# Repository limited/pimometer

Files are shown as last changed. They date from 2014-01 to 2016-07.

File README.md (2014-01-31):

pimometer
=========
=======
## Remote Thermocouple Monitor

### Goal 
PCB to report temperature from 4 k-type thermocouples over wireless, for viewing on a smartphone. 
* _Form Factor_: Raspberry Pi Shield
* _Power Source_: Initially battery powered with on/off switch. 
** Future: solar or thermoelectric generator(TEG) using heat from oven.
* _Thermocouple Measurement_: MAX31855 [Datasheet](http://datasheets.maximintegrated.com/en/ds/MAX31855.pdf) via SPI in an SO-8 package
* _Wireless Connection_: WiFi Dongle
* _Configuration/Display_: via SD Card 
** LEDs for display- 1 LED for wireless connection
* Smartphone Display: Ideally would be accessible across multiple smartphone platforms, so no native app. 
** Better to have a webserver run on the device itself, i.e. Flask

### Design
#### Raspberry Pi pinout
* Clock: 11 
* MISO: 9
* CS1: 18 
* CS2: 23
* CS3: 24
* CS4: 25
* Also need +3.3V and ground available to shield
 
#### Software Design
* When Flask receives request for current temperatures, 
o

#### Service installation
chmod 755 nodejs
sudo cp nodejs /etc/init.d
sudo update-rc.d nodejs defaults

### Avahi Installation
sudo apt-get install avahi-daemon
sudo insserv avahi-daemon

#### Cost Comparison
Component  |  Raspberry Pi  | Arduino (TC shield + wifi breakout)
-----------+----------------+-------------------------------------
Controller |   $35          |    $7
Crystal    |                |    $1
Regulator  |                |    $2
Wifi       |   $15          |    $35
SD card    |   $8           |    
------------------------------------------------------------------
Subtotal   |   $58          |    $45

TC shield
------------
4xTC       |              $32
Custom PCB |              $15?

Enclosure    |
LiPo Battery | 
LiPo Charger |

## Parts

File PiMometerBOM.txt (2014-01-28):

Partlist exported from /Users/efriedri/Dropbox/eagle/PiMometer/PiMometer.sch at 11/29/13 10:36 PM

(M) Mouser
(SF) Sparkfun

Supplier	Part      Value               Device                  Package             Description                          PROD_ID   VALUE
M		C1        10uF                10UF50V20%(1210)        1210                16V 1210 10uF 10% MLCC	       810-C3225X7R1C106K 10uF 
M		C2        0.1uF               0.1UF-100V-10%(0603)    0603-CAP            16V 0603 .1uF 5% MLCC                77-VJ0603Y104JXJPBC 0.1uF
M		C3        0.1uF               0.1UF-100V-10%(0603)    0603-CAP            16V 0603 .1uF 5% MLCC                77-VJ0603Y104JXJPBC 0.1uFM
M		C4        0.1uF               0.1UF-100V-10%(0603)    0603-CAP            16V 0603 .1uF 5% MLCC                77-VJ0603Y104JXJPBC 0.1uF
M		C5        0.1uF               0.1UF-100V-10%(0603)    0603-CAP            16V 0603 .1uF 5% MLCC                77-VJ0603Y104JXJPBC 0.1uF
M		C6        10uF                10UF50V20%(1210)        1210                16V 1210 10uF 10% MLCC               810-C3225X7R1C106K 10uF                                    
SF		GPIO1     2X132X13            2X132X13                2X13                PRT-11490                            PRT-11490                                                      
M		IC1       MAX31855            MAX31855 		      SO08      	  MAX31855KASA+                                                              
M		IC2       MAX31855            MAX31855                SO08                MAX31855KASA+                                                    
M		IC3       MAX31855            MAX31855                SO08                MAX31855KASA+                                       
M		IC4       MAX31855            MAX31855                SO08                MAX31855KASA+                                       
SF		JP1       M022.54MM_SCREWTERM M022.54MM_SCREWTERM     1X02_2.54_SCREWTERM PRT-10571				PRT-10571	                
SF		JP2       M022.54MM_SCREWTERM M022.54MM_SCREWTERM     1X02_2.54_SCREWTERM PRT-10571				PRT-10571
SF		JP3       M022.54MM_SCREWTERM M022.54MM_SCREWTERM     1X02_2.54_SCREWTERM PRT-10571				PRT-10571
SF		JP4       M022.54MM_SCREWTERM M022.54MM_SCREWTERM     1X02_2.54_SCREWTERM PRT-10571				PRT-10571
SF 		JP5       M022.54MM_SCREWTERM M022.54MM_SCREWTERM     1X02_2.54_SCREWTERM PRT-10571				PRT-10571
SF		R1        10K                 10KOHM1/10W1%(0603)0603 0603-RES            RES-00824                            PRT-11246 10K        
SF 		R2        10K                 10KOHM1/10W1%(0603)0603 0603-RES            RES-00824                            PRT-11246 10K
SF 		R3        10K                 10KOHM1/10W1%(0603)0603 0603-RES            RES-00824                            PRT-11246 10K  
SF 		R4        10K                 10KOHM1/10W1%(0603)0603 0603-RES            RES-00824                            PRT-11246 10K  
SF 		R5        10K                 10KOHM1/10W1%(0603)0603 0603-RES            RES-00824                            PRT-11246 10K  
SF 		R6        10K                 10KOHM1/10W1%(0603)0603 0603-RES            RES-00824                            PRT-11246 10K  
SF 		R7        10K                 10KOHM1/10W1%(0603)0603 0603-RES            RES-00824                            PRT-11246 10K  
SF 		R8        10K                 10KOHM1/10W1%(0603)0603 0603-RES            RES-00824                            PRT-11246 10K  
SF 		R9        10K                 10KOHM1/10W1%(0603)0603 0603-RES            RES-00824                            PRT-11246 10K  
SF 		R10       10K                 10KOHM1/10W1%(0603)0603 0603-RES            RES-00824                            PRT-11246 10K  
SF 		R11       10K                 10KOHM1/10W1%(0603)0603 0603-RES            RES-00824                            PRT-11246 10K  
N/A		STANDOFF1 STAND-OFF           STAND-OFF               STAND-OFF           #4 Stand Off                                        
N/A		STANDOFF2 STAND-OFF           STAND-OFF               STAND-OFF           #4 Stand Off                                        
N/A		STANDOFF4 STAND-OFF           STAND-OFF               STAND-OFF           #4 Stand Off

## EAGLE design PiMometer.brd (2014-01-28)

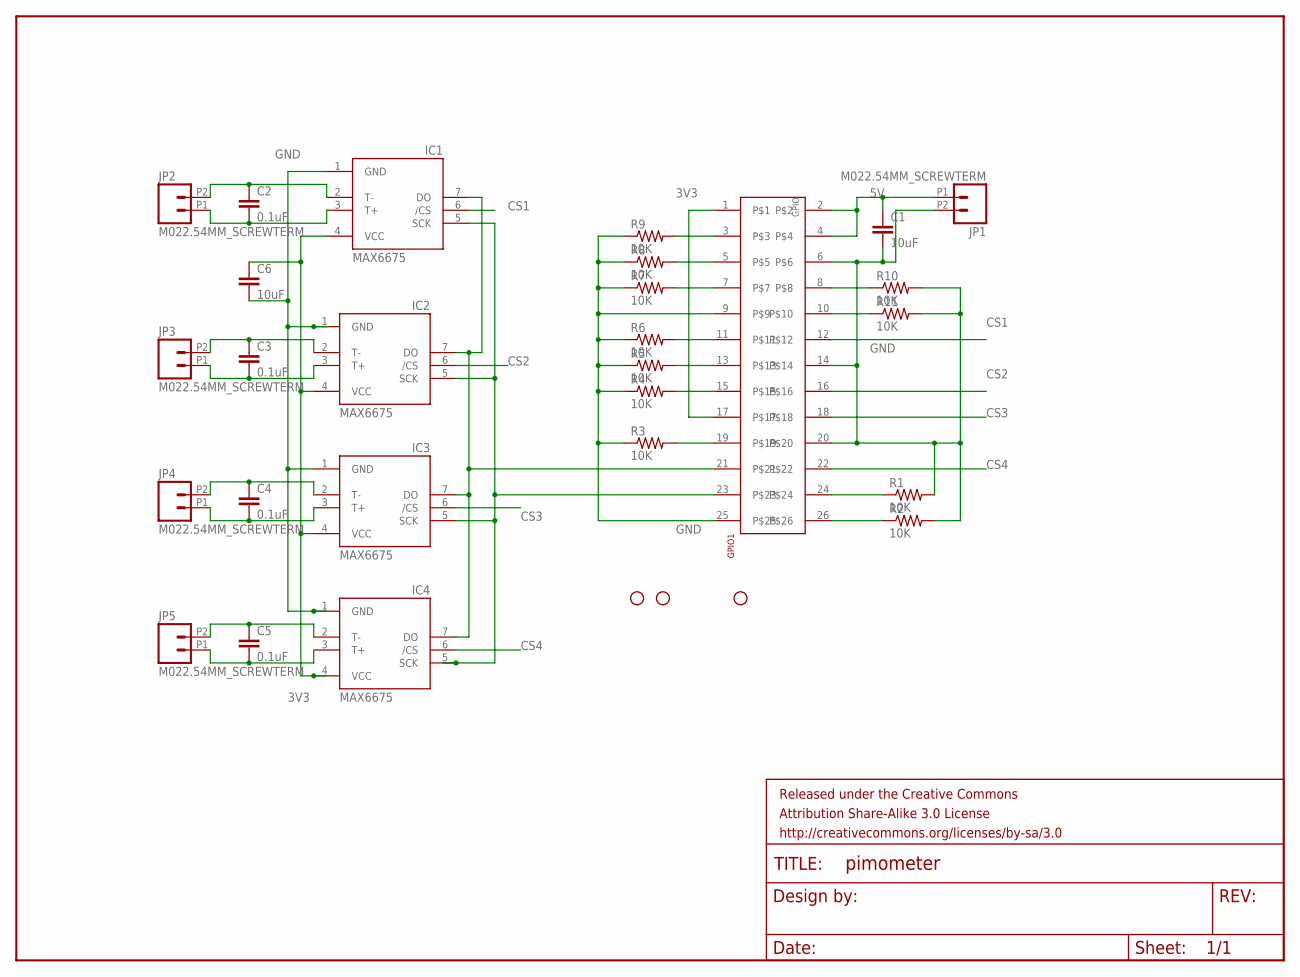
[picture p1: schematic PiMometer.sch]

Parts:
C1, C6: 10uF; 1210
C2, C3, C4, C5: 0.1uF; 0603-CAP
FRAME1: FRAME-LETTER; CREATIVE_COMMONS
GPIO1: 2X132X13; 2X13
IC1, IC2, IC3, IC4: MAX6675; SO08
JP1, JP2, JP3, JP4, JP5: M022.54MM_SCREWTERM; 1X02_2.54_SCREWTERM
R1, R2, R3, R4, R5, R6, R7, R8, R9, R10, R11: 10K; 0603-RES
STANDOFF1, STANDOFF2, STANDOFF4: STAND-OFF

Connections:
3V3: C6.1, GPIO1.1, GPIO1.17, IC1.4 (VCC), IC2.4 (VCC), IC3.4 (VCC), IC4.4 (VCC)
5V: C1.1, GPIO1.2, GPIO1.4, JP1.P1 (1)
CS1: GPIO1.12, IC1.6 (/CS)
CS2: GPIO1.16, IC2.6 (/CS)
CS3: GPIO1.18, IC3.6 (/CS)
CS4: GPIO1.22, IC4.6 (/CS)
GND: C1.2, C6.2, GPIO1.6, GPIO1.9, GPIO1.14, GPIO1.20, GPIO1.25, IC1.1 (GND), IC2.1 (GND), IC3.1 (GND), IC4.1 (GND), JP1.P2 (2), R1.2, R2.2, R3.1, R4.1, R5.1, R6.1, R7.1, R8.1, R9.1, R10.2, R11.2
unnamed: GPIO1.21, IC1.7 (DO), IC2.7 (DO), IC3.7 (DO), IC4.7 (DO)
unnamed: GPIO1.23, IC1.5 (SCK), IC2.5 (SCK), IC3.5 (SCK), IC4.5 (SCK)
unnamed: GPIO1.24, R1.1
unnamed: GPIO1.26, R2.1
unnamed: C2.1, IC1.2 (T-), JP2.P2 (2)
unnamed: C2.2, IC1.3 (T+), JP2.P1 (1)
unnamed: GPIO1.3, R9.2
unnamed: GPIO1.5, R8.2
unnamed: GPIO1.7, R7.2
unnamed: GPIO1.11, R6.2
unnamed: GPIO1.13, R5.2
unnamed: GPIO1.15, R4.2
unnamed: GPIO1.19, R3.2
unnamed: GPIO1.8, R10.1
unnamed: GPIO1.10, R11.1
unnamed: C3.1, IC2.2 (T-), JP3.P2 (2)
unnamed: C3.2, IC2.3 (T+), JP3.P1 (1)
unnamed: C4.1, IC3.2 (T-), JP4.P2 (2)
unnamed: C4.2, IC3.3 (T+), JP4.P1 (1)
unnamed: C5.1, IC4.2 (T-), JP5.P2 (2)
unnamed: C5.2, IC4.3 (T+), JP5.P1 (1)

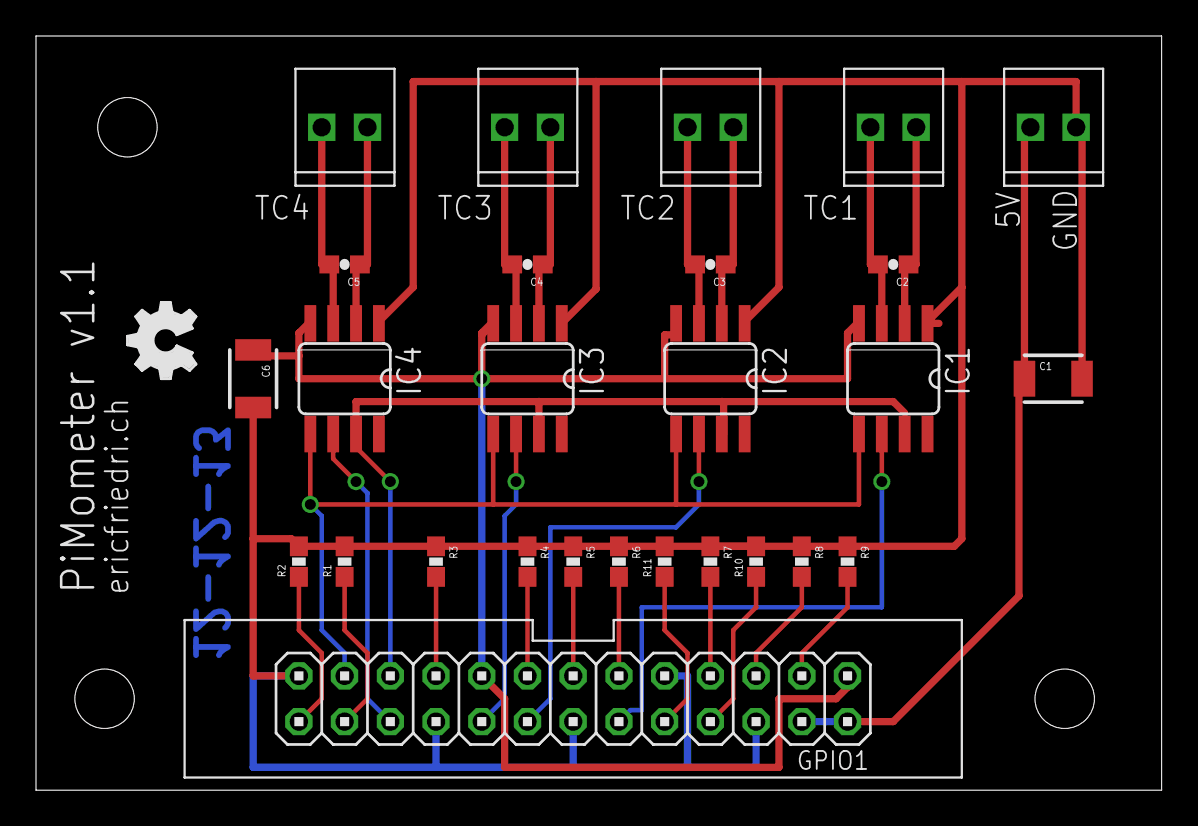
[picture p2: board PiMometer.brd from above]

Board: 2 copper layers, 62.5 x 41.9 mm, 32 parts (0 on the bottom side), 28 nets.

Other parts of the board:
U$1: OSHW_FILLX150_NOTEXT

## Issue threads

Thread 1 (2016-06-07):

Purchase

a-kress, 2016-06-07:
Is there anywhere I can purchase one of these boards? With or without components.

limited, 2016-06-08:
Not right now, sorry. Would you like to see it on Tindie or somewhere similar?

(I have one unpopulated board somewhere in my basement that I would send you, will let you know if I can find it)

a-kress, 2016-06-08:
I'd gladly pay you for it!

If not, no sweat. I may try to upload the eagle files to 123dcircuits.com.
I've never actually purchased a prototype board like this so I'm really
looking for the simplest solution.

Thanks!

On Wed, Jun 8, 2016 at 8:06 AM, Eric Friedrich <notifications@github.com>
wrote:

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

--

Adam Kress
akress.com

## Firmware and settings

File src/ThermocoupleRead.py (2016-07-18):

#!/usr/bin/env python
#
# Bitbang'd SPI interface with a MAX31855 TC->SPI device
#  Connections are:
#     CLK => 18  
#     DOUT => 23 (chip's data out, RPi's MISO)
#     CS => 24 

import RPi.GPIO as GPIO
import math
import time
import sys

MISO = 9 
CS_ARRAY = [18, 23, 24, 25]
CLK = 11 

def setupSpiPins():
    ''' Set pins as an output except MISO (Master Input, Slave Output)'''
    GPIO.setup(CLK, GPIO.OUT)
    GPIO.setup(MISO, GPIO.IN)
    for cs in CS_ARRAY:
      GPIO.setup(cs, GPIO.OUT)
    
    GPIO.output(CLK, GPIO.LOW)
    for cs in CS_ARRAY:
      GPIO.output(cs, GPIO.HIGH)
     

def readTemp(miso):
    
    tcValue = recvBits(miso, 32)
    #print "TC value: %x" % (tcValue)

    if (tcValue & 0x8):
      return 0 #"ERROR: Reserved bit 3 is 1" 

    if (tcValue & 0x20000):
      return 0 #"ERROR: Reserved bit 17 is 1" 

    if (tcValue & 0x10000):
      if (tcValue & 0x1):
        return 0 #"ERROR: Open Circuit"
      if (tcValue & 0x2):
        return 0 #"ERROR: Short to GND"
      if (tcValue & 0x4):
        return 0 #"ERROR: Short to Vcc"

    internal = (tcValue >> 4) & 0xFFF
    #print "Internal: %fC" % (internal*.0625)
    #print "Internal: %fF" % (internal*.0625*9.0/5.0+32)


    tcValue = tcValue >> 18

    temp = tcValue & 0x3FFF
    if (tcValue & 0x2000):
      temp = temp | 0xC000

    temp = temp * 0.25
    return temp
    
def recvBits(cs, numBits):
    '''Receives arbitrary number of bits'''
    retVal = 0

    # Start the read with chip select low
    GPIO.output(cs, GPIO.LOW)
    
    for bit in range(numBits):
        # Pulse clock pin 
        GPIO.output(CLK, GPIO.HIGH)
        
        # Advance input to next bit
        retVal <<= 1

        # Read 1 data bit in
        if GPIO.input(MISO):
            #print 31-bit, "1"
            retVal |= 0x1
        #else:
	#    print 31-bit, "0"
        
        GPIO.output(CLK, GPIO.LOW)
        time.sleep(.001)
    
    # Set chip select high to end the read
    GPIO.output(cs, GPIO.HIGH)

    return (retVal)

def convertTypeJToTypeK(temp):
    ''' Output temperature based on a Type J Thermocouple. 

        Theory: 
          The output temperature for a thermocouple is based on a voltage
          difference across the device. To use a Type J Thermocouple with the
          MAX31855K measurement sensor, do the following:
           1) Use the ITS-90 Type-K Direct Polynomial to find the 
              thermoelectric voltage from the reported temperature
           2) Use the ITS-90 Type-J Inverse Polynomial to find the
              temperature from the computed thermoelectric voltage
          NB: If polynomials are too hard to compute, use a lookup table 
              instead.
    '''
    volt = tcKTempTouV(temp)
    new_temp = tcuVToJTemp(volt)

def tcKTempTouV(temp):
    ''' Return thermoelectic voltage for a temperature'''
    # Type-K Coefficients for 0-1372C
    direct_coeff = [-1.7600413686e1,
                     3.8921204975e1,
                     1.8558770032e-2,
                    -9.9457592874e-5,
                     3.1840945719e-7,
                    -5.6072844889e-10,
                     5.6075059059e-13,
                    -3.2020720003e-16,
                     9.7151147152e-20,
                    -1.210472127e-23]
    a_0 =  1.185976e2
    a_1 = -1.183432e-4

    e = 0
    for (i, coeff) in enumerate(direct_coeff):
        e += coeff * pow(temp, i)

    exp = a_1 * pow(temp - 126.9686, 2)
    e += a_0 * pow(math.e, exp)
    return e

def tcuVToJTemp(volt):
    ''' Return temp across a J-Type thermocouple'''
    # high is 760-1200C, mid is 0-760C
    indirect_coeff={'high': [-3.11358187e3,
                              3.00543684e-1,
                             -9.94773230e-6,
                              1.70276630e-10,
                             -1.43033468e-15,
                              4.73886084e-21],
                    'mid': [0,
                            1.978425e-2,
                            -2.001204e-7,
                            1.036969e-11,
                            -2.549687e-16,
                            3.585153e-21,
                            -5.344285e-26,
                            5.099890e-31]}
    if volt >= 0 and volt < 42919:
        mode = 'mid'
    elif volt >= 42919:
        mode ='high'

    temp = 0
    for (i, coeff) in enumerate(indirect_coeff[mode]):
        temp += coeff * pow(volt, i)
        
    return temp

def convertCToF(temp):
    return (temp*9.0/5.0+32)
    
    
if __name__ == '__main__':
    try:
        GPIO.setmode(GPIO.BCM)
        #print "Started"
        setupSpiPins()
        #print "Setup"
        for cs in CS_ARRAY:
          val = readTemp(cs)
          #val = convertTypeJToTypeK(val)
          print str(convertCToF(val))
          #print "Temp: ", str(val*9.0/5.0+32),"F"
        GPIO.cleanup()
        sys.exit(0)
    except KeyboardInterrupt:
        GPIO.cleanup()
        sys.exit(0)

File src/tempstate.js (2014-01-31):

var config = {numChannels: 4, 
	      historySize: 30,
	      avgSize: 10,
	      updatePeriod: 1000};

var title = ["Channel 1", "Channel 2", "Channel 3", "Channel 4"];
  
function buildState() {
    var state = {};
    state.channels = [];
    for (i = 0; i < config.numChannels; i++) {
	state.channels.push({title: title[i],
			     current: 0.0,
			     min: 1000000,
			     max: 0, 
			     movingAvg: 0,
			     range: [], 
                             error: ""});
    }
    return state;
}
var tempState = buildState();

function updateStats(channel, current) {
    channel.current = current;
    channel.range.push(channel.current);

    if (current < channel.min) {
	channel.min = current;
    }

    if (current > channel.max) {
	channel.max = current
    }

    if (channel.range.length >= config.historySize) {
	channel.range.shift()
    }

    // compute moving avg over last few
    var avgWindow = channel.range.slice(-1 * config.avgSize);
    channel.movingAvg = avgWindow.reduce(function(a, b) {
	return a + b; }, 0) / avgWindow.length;
    //console.log(channel);
 }

setInterval(function() {
    var spawn = require('child_process').spawn,
        tcRead = spawn("sudo", ["./ThermocoupleRead.py"]);
    tcRead.stdout.on('data', function(data) {
      var dataArray = data.toString().split("\n");
      dataArray.slice(0,4).map(function(currentValue, index) {
        var temp = parseFloat(currentValue); 
	updateStats(tempState.channels[index], temp);
      });
    });
}, config.updatePeriod);


function getTempState() {
    return tempState;
}

module.exports.getTempState = getTempState;

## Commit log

2013-10-16 Added some CheckLiverLight case design files Started project descriptor of Remote Thermocouple Monitor
2013-12-01 Added a bunch of new projects, consolidating from Dropbox and local directories. Some personal scripts/projects from Cisco Remote Thermocouple Monitor (i.e. PiMometer) Reverse Geocache Temp Controlle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
    [PiMometer.brd, PiMometer.sch]
2013-12-12 First pass of UI code for Pimometer, built on Node.js, socket.io, and d3s
2014-01-28 Added package.json and rpi.js
    [PiMometer.brd]
2014-01-28 Filter branch
    [PiMometer.brd, PiMometer.sch]
2014-01-28 Removing RemoteThermocoupleMonitor directory
    [PiMometer.brd, PiMometer.sch]
2014-01-29 Got code working with 1 channel and MAX31855 breakout board. Issue with scope of channel variable in tempstate timer callback
    [ThermocoupleRead.py, tempstate.js]
2014-01-31 Complete Pimometer Next step: error displays?
    [ThermocoupleRead.py, tempstate.js]
2014-01-31 Fix incorrect variable name in tempstate.js Convert temp to F in ThermocoupleRead.py Start node as root for access to port 80
    [ThermocoupleRead.py, tempstate.js]

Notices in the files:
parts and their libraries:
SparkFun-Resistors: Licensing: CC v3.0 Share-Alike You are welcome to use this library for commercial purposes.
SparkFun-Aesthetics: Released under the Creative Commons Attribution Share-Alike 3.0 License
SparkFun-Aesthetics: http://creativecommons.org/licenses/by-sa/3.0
